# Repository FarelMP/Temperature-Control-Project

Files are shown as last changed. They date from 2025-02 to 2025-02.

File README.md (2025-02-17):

# Temperature-Control-Project
This is the result of the assignment of the interface and microcontroller workshop course, the project aims to measure voltage, current and tempereture while controlling brightness of halogen lamp. After all measruements, the data will visualize through node red using serial communication.

Contain included:
- Schematic and PCB layout (EAGLE).
- Node red JSON source file.
- STM32G431RBTX program for sensor reading and measurement.

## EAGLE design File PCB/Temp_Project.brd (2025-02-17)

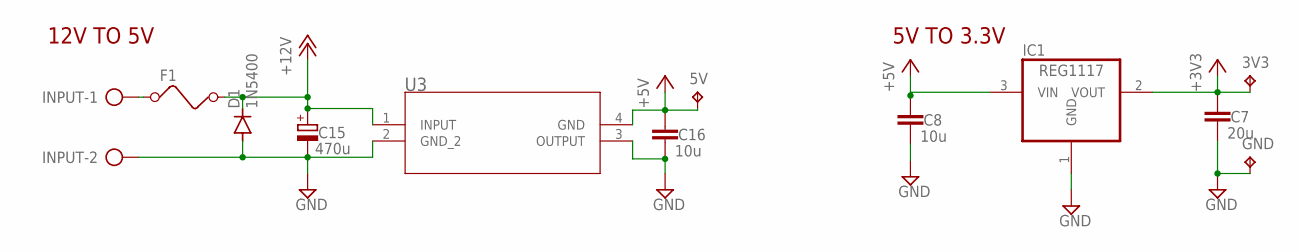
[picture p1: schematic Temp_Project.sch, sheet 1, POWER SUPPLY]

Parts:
3V3, 5V: TPPAD1-13; P1-13
C7: 20u; C0805
C8, C16: 10u; C0805
C15: 470u; E5-10,5
D1: 1N5400; DO201-15
F1: FUSE
GND: TPPAD1-13; P1-13
IC1: REG1117; SOT223
INPUT: AK500/2-H
U3: LM7805MPX/NOPBDCY4_TEX; DCY4_TEX

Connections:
+3V3: 3V3.TP, C7.1, IC1.2 (VOUT); also elsewhere on the board
+5V: 5V.TP, C8.1, C16.1, IC1.3 (VIN), U3.4 (GND); also elsewhere on the board
+12V: C15.+, D1.C, F1.2, U3.1 (INPUT); also elsewhere on the board
GND: C7.2, C8.2, C15.-, C16.2, D1.A, GND.TP, IC1.1 (GND), INPUT.2, U3.2 (GND_2), U3.3 (OUTPUT); also elsewhere on the board
unnamed: F1.1, INPUT.1

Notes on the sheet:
12V TO 5V
5V TO 3.3V

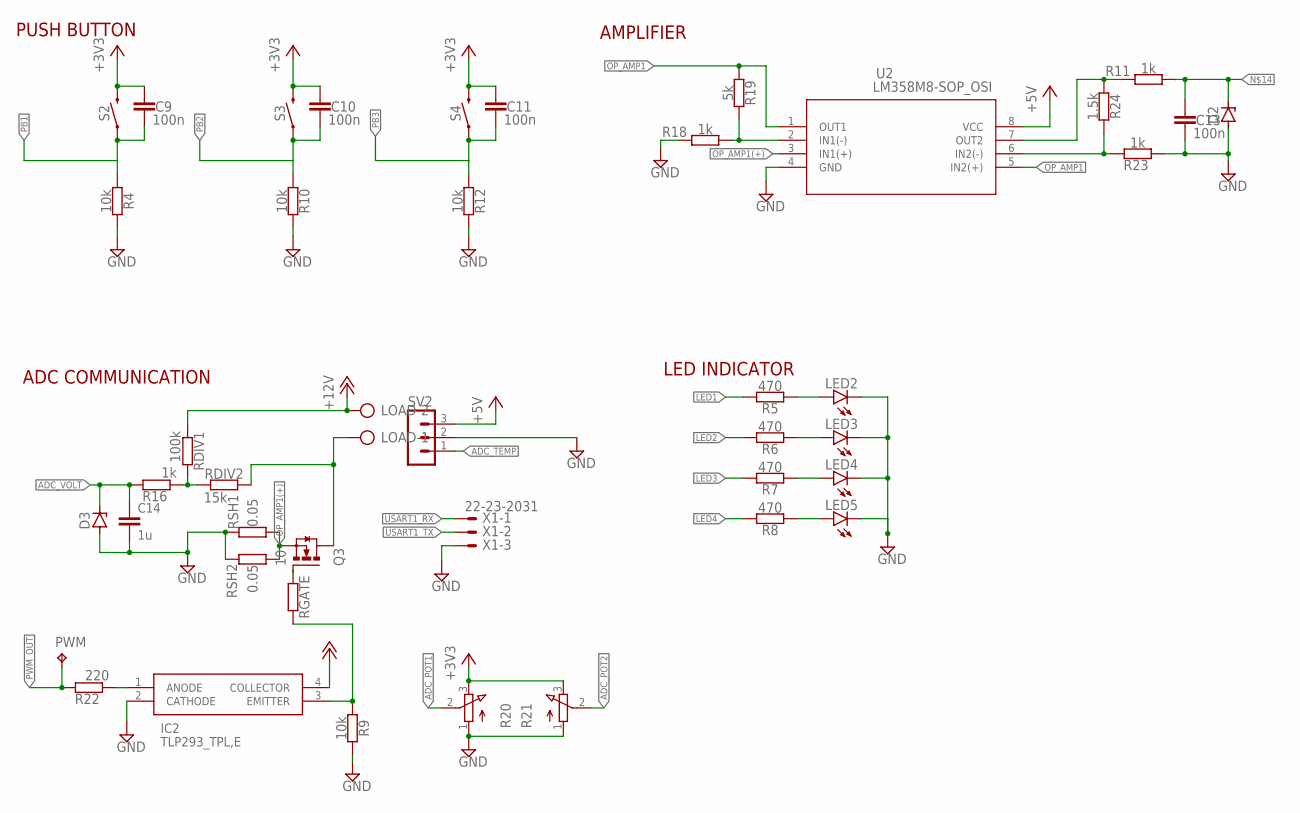
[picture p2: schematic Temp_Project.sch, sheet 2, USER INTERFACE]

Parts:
C9, C10, C11, C13: 100n; C0805
C14: 1u; C0805
D2, D3: ZENER 3V3; SOD80C
IC2: TLP293_TPL,E; SOIC127P700X220-4N
LED2, LED3, LED4, LED5: LED3MM
LOAD: AK500/2-H
PWM: TPPAD1-13; P1-13
Q3: IRFZ44N; SOT223
R4, R9, R10, R12: 10k; R0805
R5, R6, R7, R8: 470; R0805
R11, R16, R18, R23: 1k; R0805
R19: 5k; R0805
R20, R21: 3RP/1610N
R22: 220; R0805
R24: 1.5k; R0805
RDIV1: 100k; R0805
RDIV2: 15k; R0805
RGATE: 10; R0805
RSH1, RSH2: 0.05; 0617/22
S2, S3, S4: MOMENTARY-SWITCH-SPST-SMD-6.0X3.5MM; TACTILE_SWITCH_SMD_6.0X3.5MM
SV2: MA03-1
U2: LM358M8-SOP_OSI; 8-SOP_OSI
X1: 22-23-2031

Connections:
+3V3: C9.1, C10.1, C11.1, R20.3 (E), R21.3 (E), S2.2, S3.2, S4.2; also elsewhere on the board
+5V: SV2.3, U2.8 (VCC); also elsewhere on the board
+12V: IC2.4 (COLLECTOR), LOAD.2, RDIV1.1; also elsewhere on the board
ADC_CUR: R11.2, R24.1, U2.7 (OUT2); also elsewhere on the board
ADC_POT1: R20.2 (S); also elsewhere on the board
ADC_POT2: R21.2 (S); also elsewhere on the board
ADC_TEMP: SV2.1; also elsewhere on the board
ADC_VOLT: C14.1, D3.C, R16.2; also elsewhere on the board
GND: C13.2, C14.2, D2.A, D3.A, IC2.2 (CATHODE), LED2.K (C), LED3.K (C), LED4.K (C), LED5.K (C), R4.1, R9.1, R10.1, R12.1, R18.2, R20.1 (A), R21.1 (A), R23.1, RSH1.1, RSH2.1, SV2.2, U2.4 (GND), X1.3; also elsewhere on the board
LED1: R5.1; also elsewhere on the board
LED2: R6.1; also elsewhere on the board
LED3: R7.1; also elsewhere on the board
LED4: R8.1; also elsewhere on the board
unnamed: LED2.A, R5.2
unnamed: LED3.A, R6.2
unnamed: LED4.A, R7.2
unnamed: LED5.A, R8.2
unnamed: IC2.1 (ANODE), R22.1
unnamed: Q3.1 (G), RGATE.1
unnamed: LOAD.1, Q3.2 (D), Q3.4 (D), RDIV2.2
unnamed: IC2.3 (EMITTER), R9.2, RGATE.2
unnamed: C13.1, D2.C, R11.1
unnamed: R18.1, R19.1, U2.2 (IN1(-))
unnamed: R16.1, RDIV1.2, RDIV2.1
unnamed: R23.2, R24.2, U2.6 (IN2(-))
OP_AMP1: R19.2, U2.1 (OUT1), U2.5 (IN2(+))
OP_AMP1(+): Q3.3 (S), RSH1.2, RSH2.2, U2.3 (IN1(+))
PB1: C9.2, R4.2, S2.1; also elsewhere on the board
PB2: C10.2, R10.2, S3.1; also elsewhere on the board
PB3: C11.2, R12.2, S4.1; also elsewhere on the board
PWM_OUT: PWM.TP, R22.2; also elsewhere on the board
USART1_RX: X1.1; also elsewhere on the board
USART1_TX: X1.2; also elsewhere on the board

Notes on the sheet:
PUSH BUTTON
AMPLIFIER
ADC COMMUNICATION
LED INDICATOR

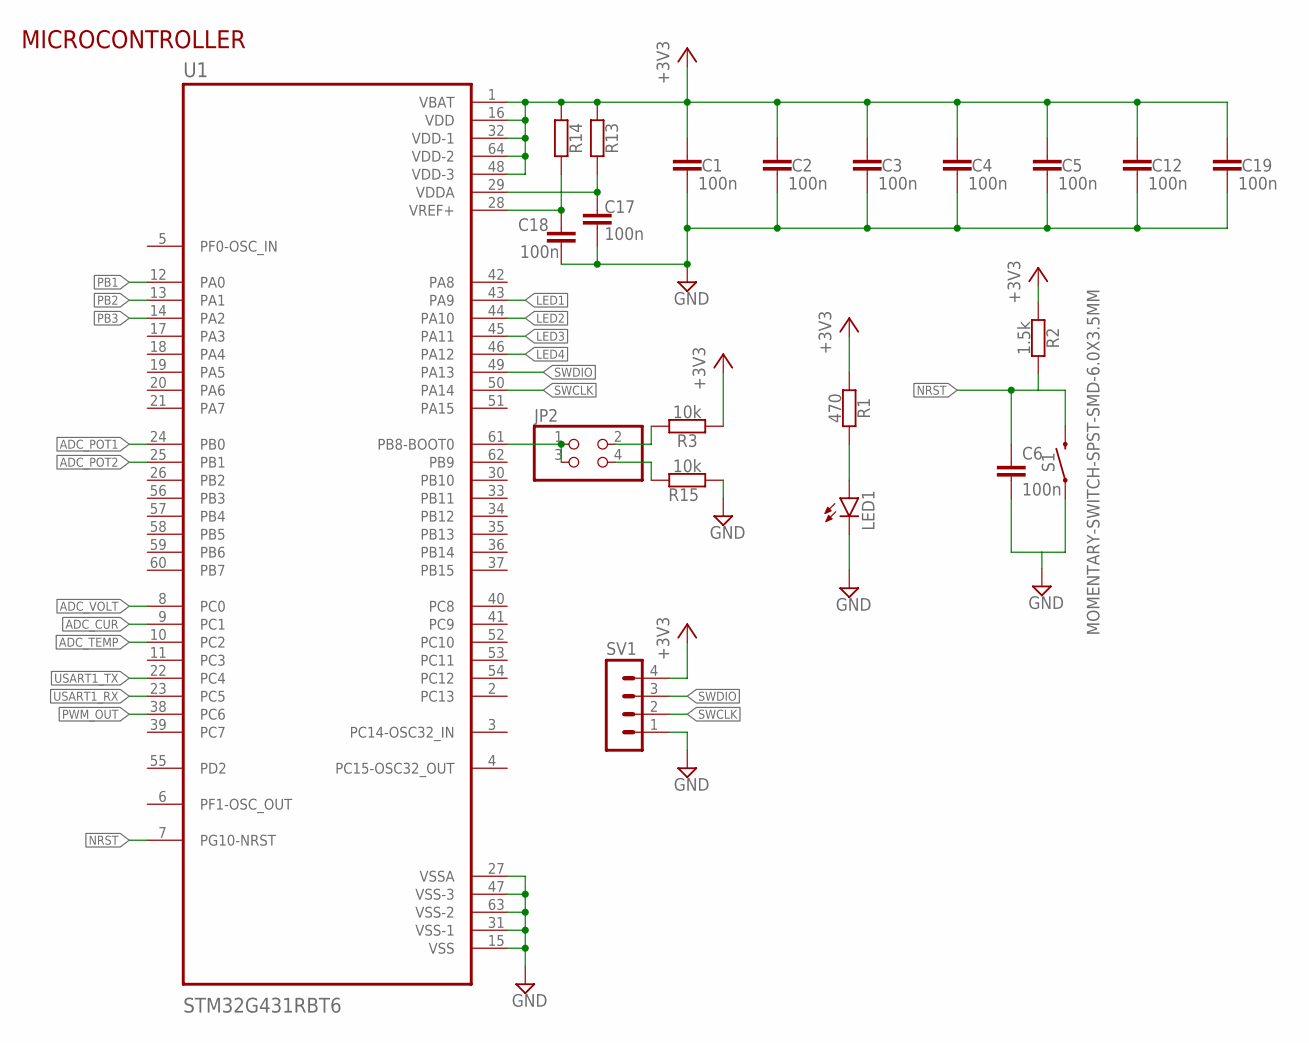
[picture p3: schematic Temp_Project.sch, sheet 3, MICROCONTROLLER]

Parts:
C1, C2, C3, C4, C5, C6, C12, C17, C18, C19: 100n; C0805
JP2: PINHD-2X2; 2X02
LED1: LEDCHIPLED_0805; CHIPLED_0805
R1: 470; R0805
R2: 1.5k; R0805
R3, R15: 10k; R0805
R13, R14: R-EU_R0603; R0603
S1: MOMENTARY-SWITCH-SPST-SMD-6.0X3.5MM; TACTILE_SWITCH_SMD_6.0X3.5MM
SV1: MA04-1
U1: STM32G431RBT6; QFP50P1200X1200X160-64N

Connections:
+3V3: C1.1, C2.1, C3.1, C4.1, C5.1, C12.1, C19.1, R1.1, R2.1, R3.1, R13.2, R14.2, SV1.4, U1.1 (VBAT), U1.16 (VDD), U1.32 (VDD-1), U1.48 (VDD-3), U1.64 (VDD-2); also elsewhere on the board
ADC_CUR: U1.9 (PC1); also elsewhere on the board
ADC_POT1: U1.24 (PB0); also elsewhere on the board
ADC_POT2: U1.25 (PB1); also elsewhere on the board
ADC_TEMP: U1.10 (PC2); also elsewhere on the board
ADC_VOLT: U1.8 (PC0); also elsewhere on the board
GND: C1.2, C2.2, C3.2, C4.2, C5.2, C6.2, C12.2, C17.2, C18.2, C19.2, LED1.C, R15.2, S1.1, SV1.1, U1.15 (VSS), U1.27 (VSSA), U1.31 (VSS-1), U1.47 (VSS-3), U1.63 (VSS-2); also elsewhere on the board
LED1: U1.43 (PA9); also elsewhere on the board
LED2: U1.44 (PA10); also elsewhere on the board
LED3: U1.45 (PA11); also elsewhere on the board
LED4: U1.46 (PA12); also elsewhere on the board
unnamed: LED1.A, R1.2
unnamed: JP2.1, JP2.3, U1.61 (PB8-BOOT0)
unnamed: JP2.2, R3.2
unnamed: JP2.4, R15.1
unnamed: C17.1, R13.1, U1.29 (VDDA)
unnamed: C18.1, R14.1, U1.28 (VREF+)
NRST: C6.1, R2.2, S1.2, U1.7 (PG10-NRST)
PB1: U1.12 (PA0); also elsewhere on the board
PB2: U1.13 (PA1); also elsewhere on the board
PB3: U1.14 (PA2); also elsewhere on the board
PWM_OUT: U1.38 (PC6); also elsewhere on the board
SWCLK: SV1.2, U1.50 (PA14)
SWDIO: SV1.3, U1.49 (PA13)
USART1_RX: U1.23 (PC5); also elsewhere on the board
USART1_TX: U1.22 (PC4); also elsewhere on the board

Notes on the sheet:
MICROCONTROLLER

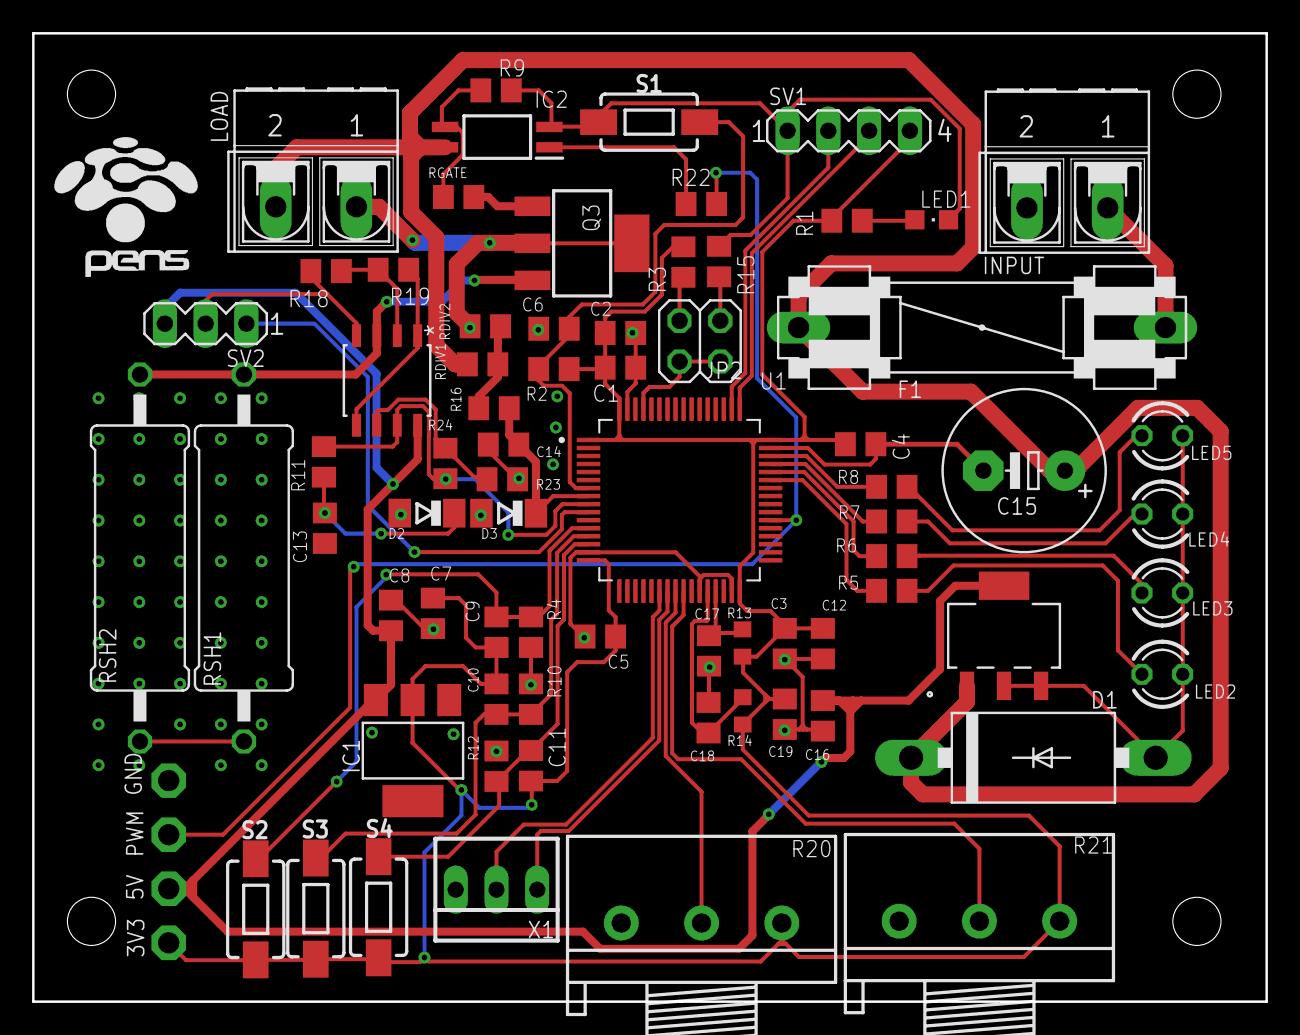
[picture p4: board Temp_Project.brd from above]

Board: 2 copper layers, 76.8 x 60.3 mm, 76 parts (0 on the bottom side), 43 nets.

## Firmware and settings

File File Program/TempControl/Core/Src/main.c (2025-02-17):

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
/* Includes ------------------------------------------------------------------*/
#include "main.h"
#include "adc.h"
#include "dma.h"
#include "tim.h"
#include "usart.h"
#include "gpio.h"

/* USER CODE BEGIN Includes */
#include "Calculation.h"
#include "Communication.h"
/* USER CODE END Includes */


/* USER CODE BEGIN PV */
	uint16_t ADC_Val[5];
	State *temp = &state;
	int duty = 5000;
	extern int flag_msg;
	extern char rcv_data[15];
/* USER CODE END PV */

void SystemClock_Config(void);
/* USER CODE BEGIN 0 */
//void HAL_UART_RxCpltCallback(UART_HandleTypeDef *huart) {
//    if (huart->Instance == huart1.Instance) {
//        parseData();
//        HAL_UART_Receive_IT(&huart1, (uint8_t*)&rcv_data, 50);
//    }
//}
/* USER CODE END 0 */

/**
  * @brief  The application entry point.
  * @retval int
  */
int main(void)
{

  /* MCU Configuration--------------------------------------------------------*/

  /* Reset of all peripherals, Initializes the Flash interface and the Systick. */
  HAL_Init();

  /* Configure the system clock */
  SystemClock_Config();

  /* Initialize all configured peripherals */
  MX_GPIO_Init();
  MX_DMA_Init();
  MX_ADC1_Init();
  MX_TIM3_Init();
  MX_USART1_UART_Init();
  MX_TIM2_Init();
  /* USER CODE BEGIN 2 */
  HAL_ADC_Start_DMA(&hadc1, (uint32_t*)&ADC_Val, 5);
  HAL_UART_Receive_IT(&huart1, (uint8_t*)&rcv_data, 15);
  HAL_TIM_PWM_Start(&htim3, TIM_CHANNEL_1);
  HAL_TIM_Base_Start_IT(&htim2);
  temp->mode_set = 'A';
  temp->StartStop = 'C';
  HAL_GPIO_WritePin(LED_MODE_GPIO_Port, LED_MODE_Pin, 1);
  /* USER CODE END 2 */

  /* Infinite loop */
  /* USER CODE BEGIN WHILE */
  while (1)
  {
    /* USER CODE END WHILE */

    /* USER CODE BEGIN 3 */
	  if(flag_msg == 1){
		  DataSend();
		  flag_msg = 0;
	  }
	  HAL_GPIO_WritePin(LED_GPIO_Port, LED_Pin, 1);
	  __HAL_TIM_SET_COMPARE(&htim3, TIM_CHANNEL_1,duty);
	  adc_conv();
	  parseData();
	  HAL_Delay(100);
  }
  /* USER CODE END 3 */
}

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


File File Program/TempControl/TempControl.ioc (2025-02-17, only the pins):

Mcu.UserName=STM32G431RBTx
PA0.GPIO_Label=PB_Mode
PA0.Signal=GPXTI0
PA1.GPIO_Label=PB_StartStop
PA1.Signal=GPXTI1
PA10.GPIO_Label=LED_STOPRUN
PA10.Signal=GPIO_Output
PA11.GPIO_Label=LED_SETPOINT
PA11.Signal=GPIO_Output
PA12.GPIO_Label=LED
PA12.Signal=GPIO_Output
PA2.GPIO_Label=Reset_state
PA2.Signal=GPXTI2
PA9.GPIO_Label=LED_MODE
PA9.Signal=GPIO_Output
PB0.GPIO_Label=POT_TIMER
PB0.Signal=ADC1_IN15
PB1.GPIO_Label=POT_SETPOINT
PB1.Signal=ADC1_IN12
PC0.GPIO_Label=ADC_VOLT
PC0.Signal=ADC1_IN6
PC1.GPIO_Label=ADC_CUR
PC1.Signal=ADC1_IN7
PC2.GPIO_Label=ADC_TEMP
PC2.Signal=ADC1_IN8
PC4.Signal=USART1_TX
PC5.Signal=USART1_RX
PC6.GPIO_Label=PWM_GEN
PC6.Signal=S_TIM3_CH1

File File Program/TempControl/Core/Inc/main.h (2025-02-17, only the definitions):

#define ADC_VOLT_Pin GPIO_PIN_0
#define ADC_VOLT_GPIO_Port GPIOC
#define ADC_CUR_Pin GPIO_PIN_1
#define ADC_CUR_GPIO_Port GPIOC
#define ADC_TEMP_Pin GPIO_PIN_2
#define ADC_TEMP_GPIO_Port GPIOC
#define PB_Mode_Pin GPIO_PIN_0
#define PB_Mode_GPIO_Port GPIOA
#define PB_Mode_EXTI_IRQn EXTI0_IRQn
#define PB_StartStop_Pin GPIO_PIN_1
#define PB_StartStop_GPIO_Port GPIOA
#define PB_StartStop_EXTI_IRQn EXTI1_IRQn
#define Reset_state_Pin GPIO_PIN_2
#define Reset_state_GPIO_Port GPIOA
#define Reset_state_EXTI_IRQn EXTI2_IRQn
#define POT_TIMER_Pin GPIO_PIN_0
#define POT_TIMER_GPIO_Port GPIOB
#define POT_SETPOINT_Pin GPIO_PIN_1
#define POT_SETPOINT_GPIO_Port GPIOB
#define PWM_GEN_Pin GPIO_PIN_6
#define PWM_GEN_GPIO_Port GPIOC
#define LED_MODE_Pin GPIO_PIN_9
#define LED_MODE_GPIO_Port GPIOA
#define LED_STOPRUN_Pin GPIO_PIN_10
#define LED_STOPRUN_GPIO_Port GPIOA
#define LED_SETPOINT_Pin GPIO_PIN_11
#define LED_SETPOINT_GPIO_Port GPIOA
#define LED_Pin GPIO_PIN_12
#define LED_GPIO_Port GPIOA

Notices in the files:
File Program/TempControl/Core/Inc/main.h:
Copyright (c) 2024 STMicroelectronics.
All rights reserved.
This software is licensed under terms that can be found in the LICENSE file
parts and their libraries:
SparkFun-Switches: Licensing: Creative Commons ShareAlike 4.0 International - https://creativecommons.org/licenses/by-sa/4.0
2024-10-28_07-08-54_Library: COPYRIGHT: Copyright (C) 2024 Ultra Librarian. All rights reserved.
